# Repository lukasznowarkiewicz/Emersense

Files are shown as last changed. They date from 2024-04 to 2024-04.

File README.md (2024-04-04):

# Emersense - Emergency Vehicle Detection System
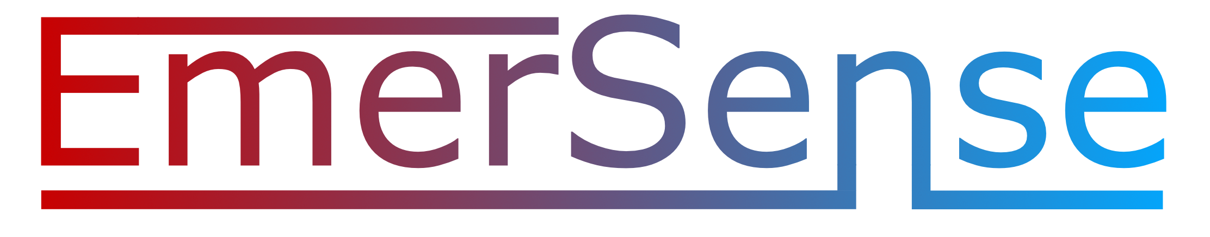
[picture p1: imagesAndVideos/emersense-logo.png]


## Introduction

Emersense is an innovative project developed by a group of dedicated students from Poznan University of Technology. Initiated during the challenging times of the pandemic, this project was brought to life entirely remotely by a team of four members located in four different cities across Poland. The project was realized as part of a competition organized by Enactus Poland, within the framework of the Enactus student organization, which promotes socially responsible projects.

The primary issue that Emersense aims to address is the often too-late response to an approaching emergency vehicle. This problem poses a significant risk not only to the efficiency of emergency services but also to the safety of both the emergency responders and the general public. By leveraging advanced technology, Emersense seeks to provide a timely warning about approaching emergency vehicles, thereby improving response times and reducing the potential for accidents.

## Solution Overview

The core of the Emersense project is a device that uses microphone data to detect emergency vehicle sirens amidst urban noise. It distinguishes these sirens from other sounds such as street noise and engine sounds, and informs the driver of their presence.

- **Siren Detection:** Utilizes signal processing to identify emergency vehicle sirens.
- **Driver Alert:** Notifies the driver through auditory and visual signals.

## Initial Trials on a PC

At the start, we gathered lots of different siren sounds from the internet to build a sound database for Emersense. We quickly found out there's a huge variety of siren sounds. These sounds not only change from one emergency vehicle to another but also differ a lot between countries. There wasn’t even a standard for sirens within the EU. Despite these challenges, we began with the easiest siren sounds to recognize: the sweep and two-tone sirens.

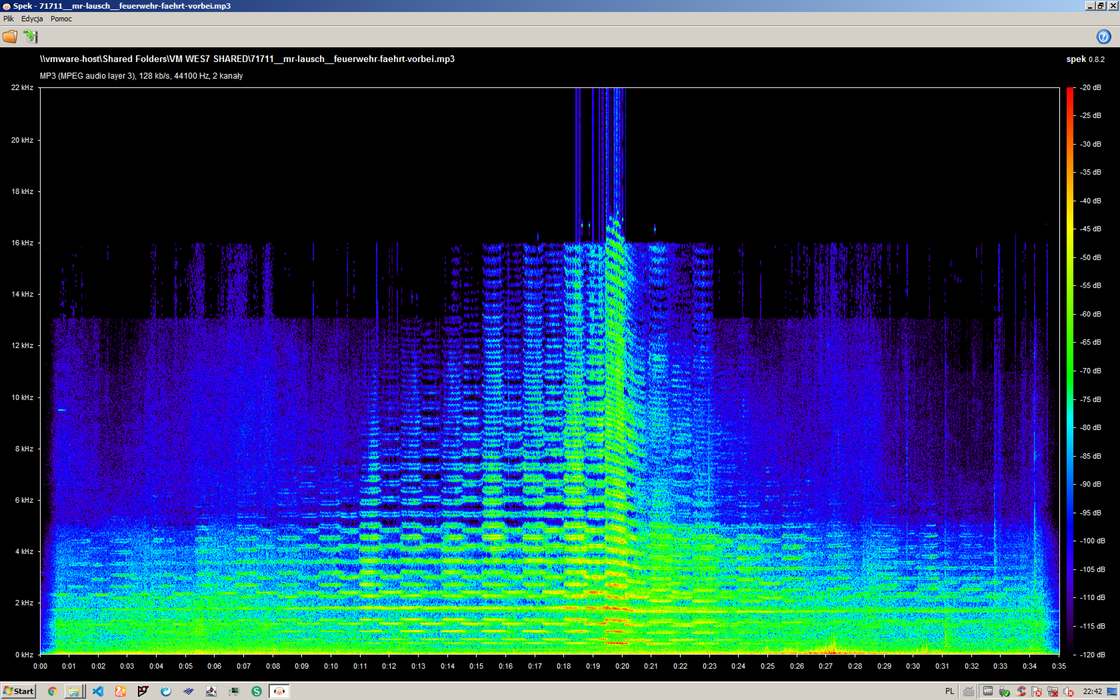
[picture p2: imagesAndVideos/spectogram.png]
Spectrogram of siren


Our first try at figuring out the siren sounds used the FFT (Fast Fourier Transform) library on a computer with an 8-core Intel Core i7 processor. But, we soon realized it was too complex to process the sounds in real time on this setup. So, we switched to the DFT (Discrete Fourier Transform), which was faster and allowed us to make our first successful programs that could recognize two-tone sirens.

Knowing we couldn’t use Python code directly on a microcontroller for the final product, we started to look into low-power hardware that could work for the Emersense device. This was a big step because it helped us focus on finding a solution that could actually be built into a real, working device.

## Trials on the DevKit

After our initial success, we started writing similar code in C for the ESP32 microcontroller. Our first goal was to get a correct spectrum of the signal received from the microphone. 

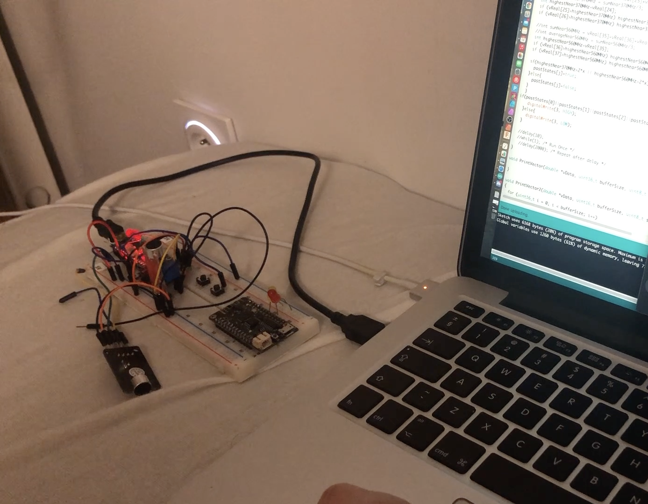
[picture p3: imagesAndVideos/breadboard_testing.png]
Breadboard testing


We soon realized that an electret microphone with an operational amplifier connected to an analog input was giving very inconsistent results. After trying out three more microphone modules, which all produced similarly poor outcomes, we switched to a MEMS microphone that uses the I2S bus - the INMP441. 

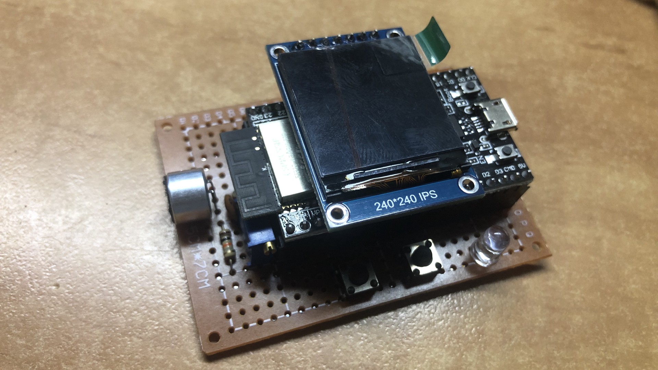
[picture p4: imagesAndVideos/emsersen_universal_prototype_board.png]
DevKit testing


Eventually, we managed to get preliminarily satisfying results and programmed it to recognize one type of two-tone siren.

https://github.com/lukasznowarkiewicz/Emersense/assets/82212257/3abe5127-96e8-427c-9536-c156f4cf9e74

## Device on a Custom PCB

As the project evolved, it became necessary for the device not only to function efficiently but also to have an appealing marketing appearance. This required moving away from the mess of wires on breadboards and prototype boards and towards giving the device a sensible shape on a custom PCB, along with a fitting enclosure.

### PCB Design

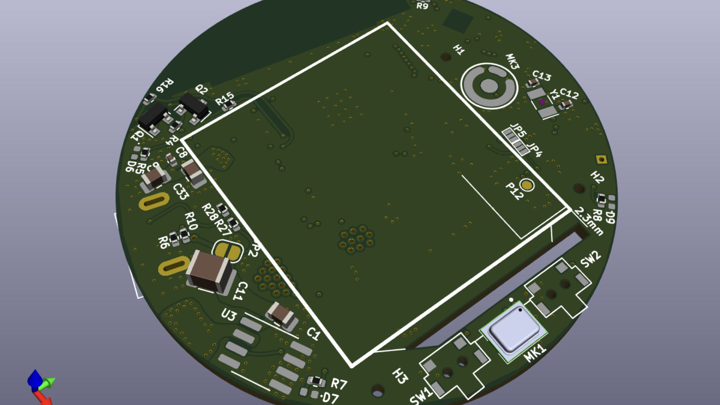
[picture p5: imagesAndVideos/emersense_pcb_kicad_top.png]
PCB Top View

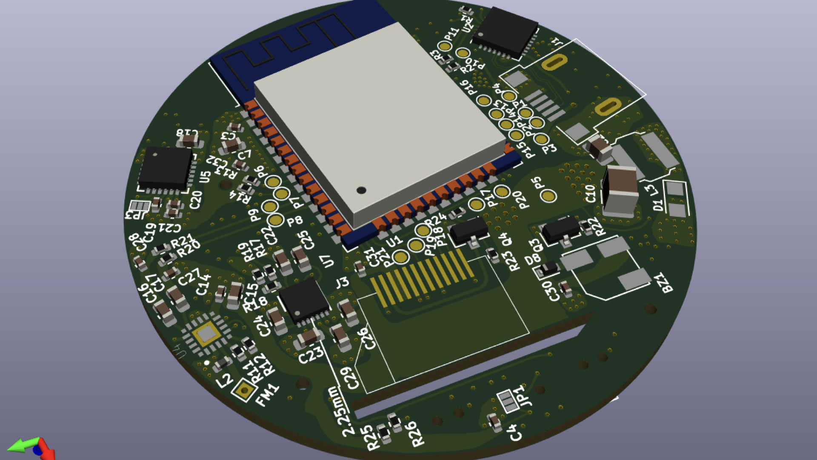
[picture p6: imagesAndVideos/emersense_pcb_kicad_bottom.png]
PCB Bottom View

Schematic

- **Software:** The PCB was designed in KiCad 5.
- **Components:**
  - **ESP32 Module:** Core processing unit.
  - **CP2102N:** For USB connectivity, allowing programming and data reading through the console.
  - **XL1509:** A converter for stepping down from 5V to 3.3V.
  - **SI4713 FM Transmitter with RDS:** We planned to generate an 'Traffic' RDS signal, which could switch nearby car radios to a traffic channel to broadcast information about the approaching emergency vehicle.
  - **MPU-6050:** For activating energy-saving mode when the vehicle is stationary for an extended period.
  - **INMP441 Digital Microphone and a Legacy Electret Microphone with Amplifier:** To test if the PCB, without the mess of wires, would collect fewer interferences.
  - **SPI 1.3 inch LCD Display (240x240 pixels) with ST7789s Controller.**
- **Shape and Assembly:** The PCB was designed in a round form to accommodate two versions of the device. It was ordered from JLCPCB, with parts from LCSC and manually assembled using a hand-operated pick and place machine.

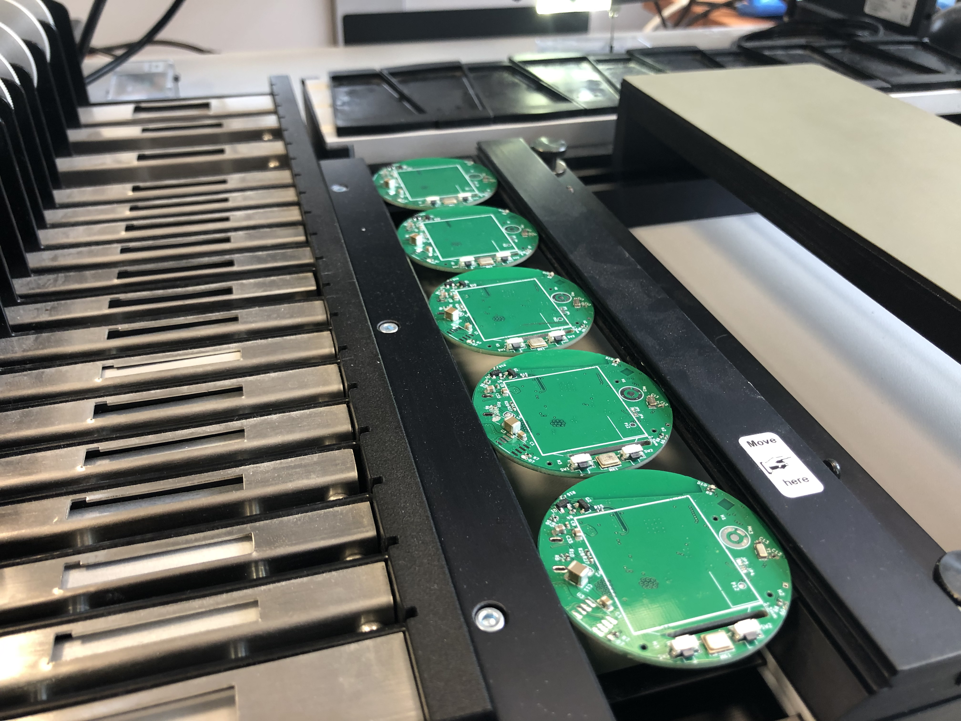
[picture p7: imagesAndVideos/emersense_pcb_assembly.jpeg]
PCB Assembly


https://github.com/lukasznowarkiewicz/Emersense/assets/82212257/2ed6d327-44b5-4cf7-a69e-9ff8332732e1

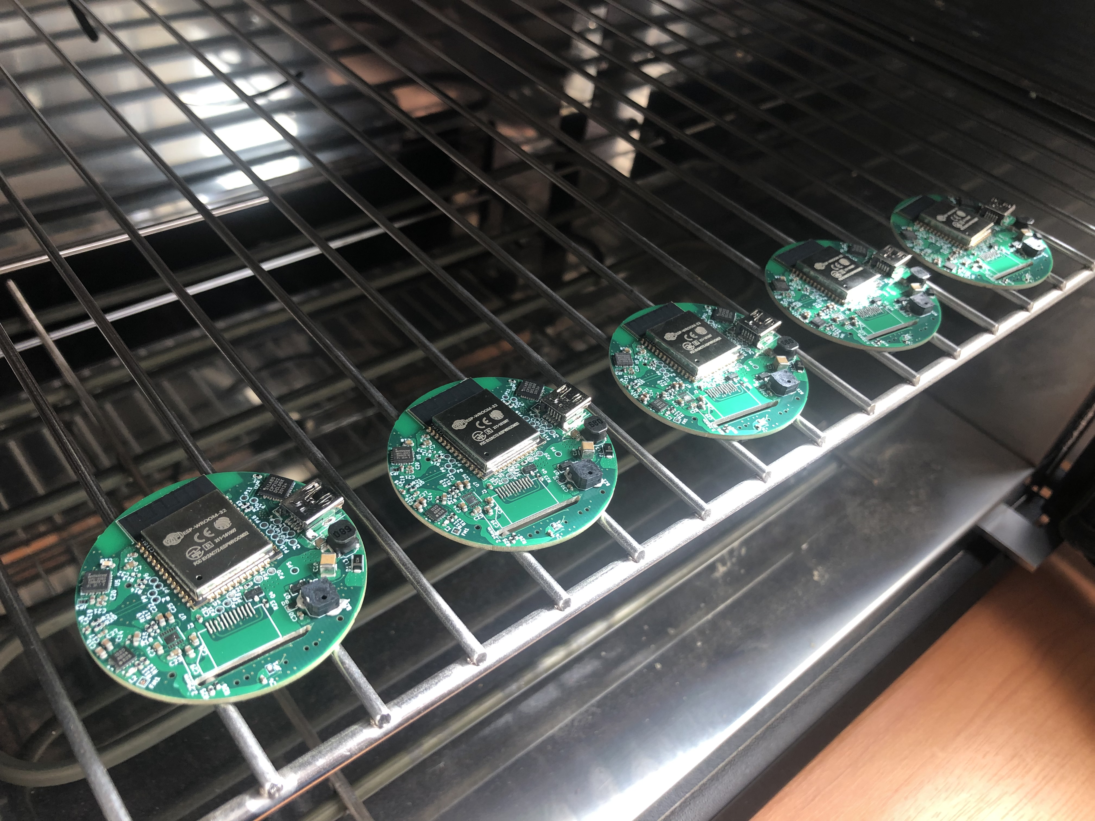
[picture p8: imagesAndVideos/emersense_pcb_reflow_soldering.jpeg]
Reflow Soldering


### Enclosure Design

- **Software:** Designed in Fusion 360.
- **Versions:** Two variants were created - one to be mounted on the windshield and another to be inserted into the cigarette lighter socket.
- **Manufacturing:** The enclosures were printed on an Anycubic Photon S SLA printer and cured under a UV nail lamp for hardening.

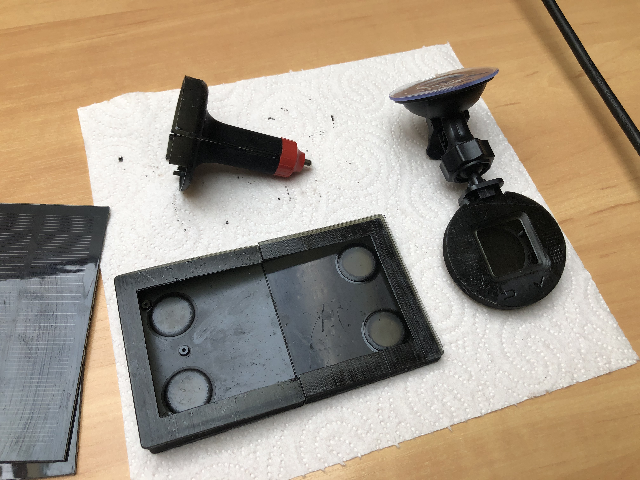
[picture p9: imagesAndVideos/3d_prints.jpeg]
3D Prints

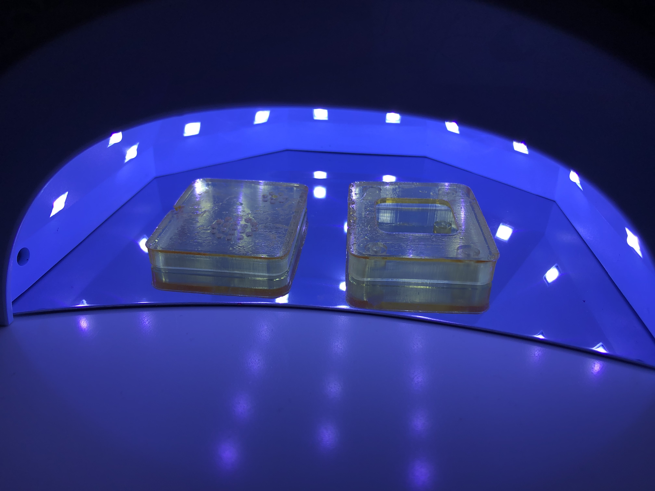
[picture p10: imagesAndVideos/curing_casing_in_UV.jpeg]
Curing Casing in UV

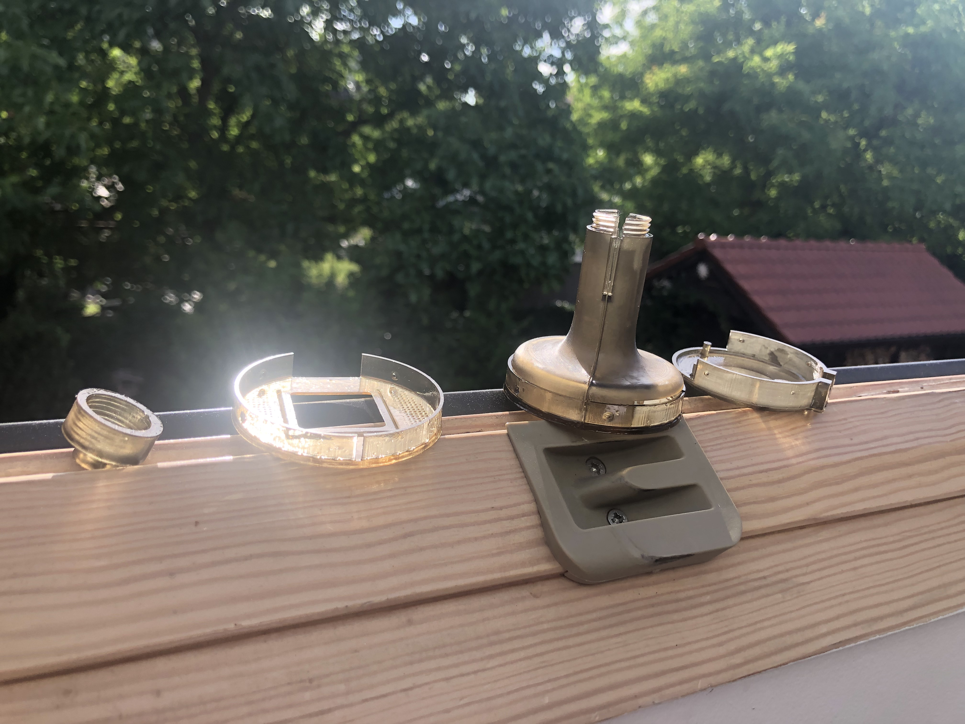
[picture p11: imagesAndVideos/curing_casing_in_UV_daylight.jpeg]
Curing Casing in UV Daylight


This stage marked a significant advancement towards finalizing the product, focusing on both functionality and aesthetics.

## Testing and Further Work

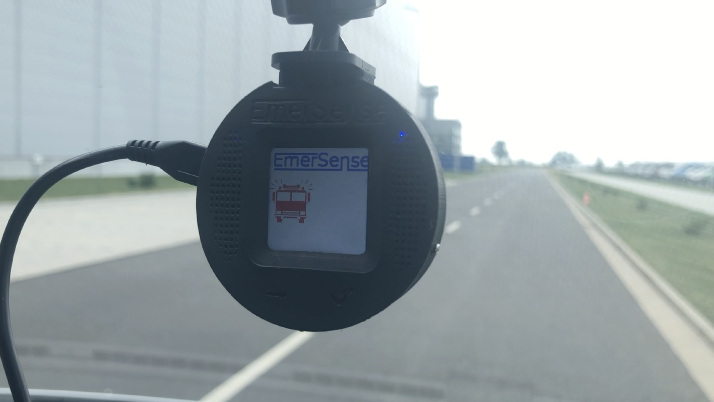
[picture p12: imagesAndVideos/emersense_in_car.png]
Testing in Car

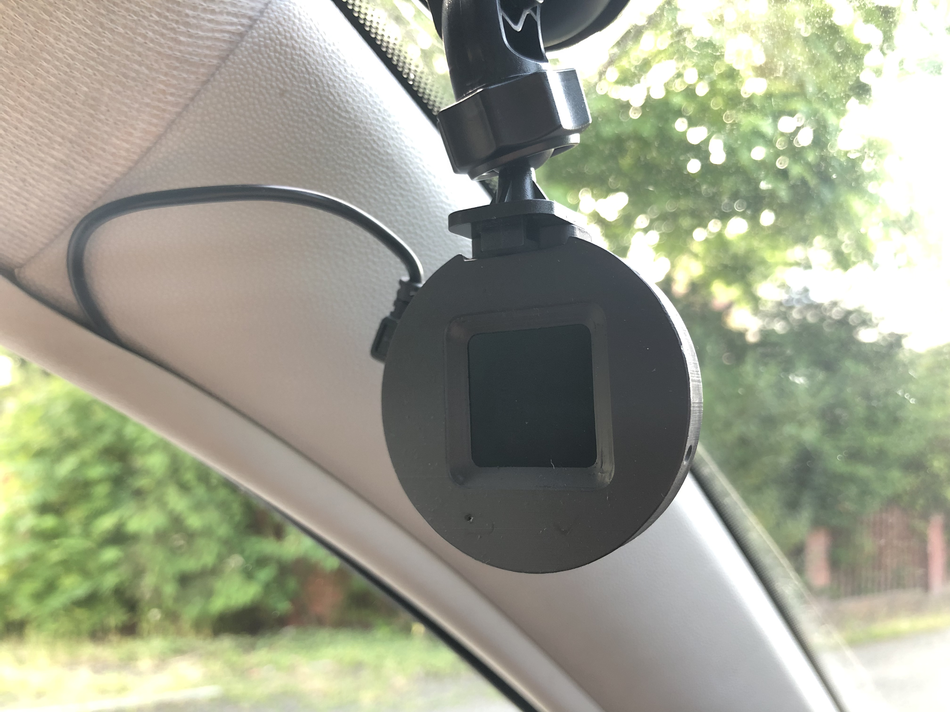
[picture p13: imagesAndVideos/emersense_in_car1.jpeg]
In-Car Device


This phase was particularly challenging. We were focused on improving the software, but progress was slow. Even with relatively simple sirens, it was difficult to balance the system's sensitivity to quickly detect sirens without being triggered by random noises. More accurate methods, like the autocorrelation function between the spectrum of a reference signal and the captured signal, were computationally complex, and we couldn't implement them to work in real-time.

At the same time, the competition, which emphasized presenting the project rather than its operational success, demanded a significant amount of time for preparing presentations and other materials. This took away valuable time that could have been spent on development. Moreover, a complete misunderstanding of the problem we were working on and what it takes to work on such projects by the leadership of the student organization didn't make things easier.

https://github.com/lukasznowarkiewicz/Emersense/assets/82212257/557e5657-ebb7-40b5-8d4b-21e4bb15feb9

Considering all these challenges, after presenting our project at the competition, we decided to close the project. Interestingly, after we had stopped working on it, the rector of the Poznan University of Technology showed interest in the device, having heard about it in local TV news. He wanted to assemble a team of doctors and PhD students to assist in the project. However, by that time, we had already concluded the project, seeing no further prospects for it. This experience was a valuable lesson on how institutions like universities can sometimes fall short in supporting such projects.

## Summary - Conclusions

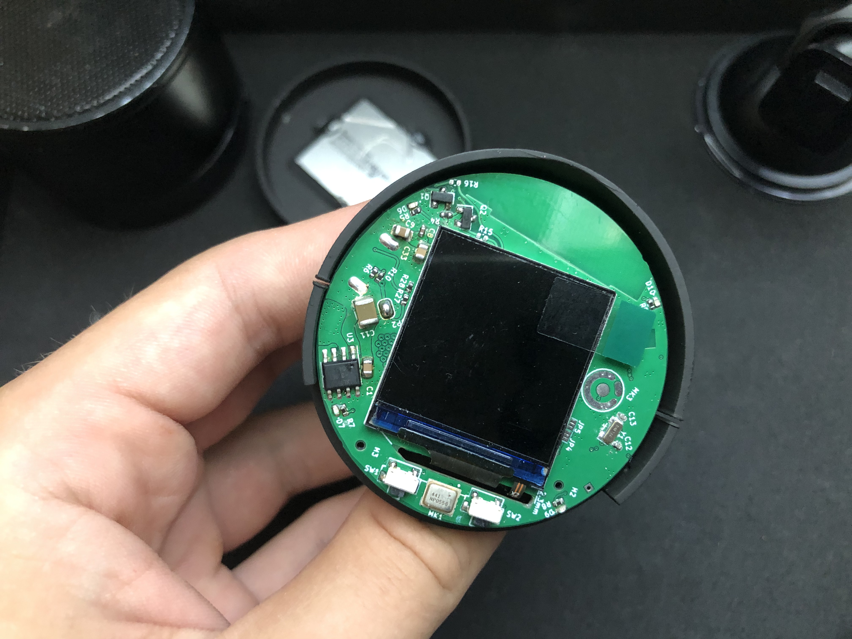
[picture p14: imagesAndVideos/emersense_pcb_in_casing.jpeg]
PCB in Casing

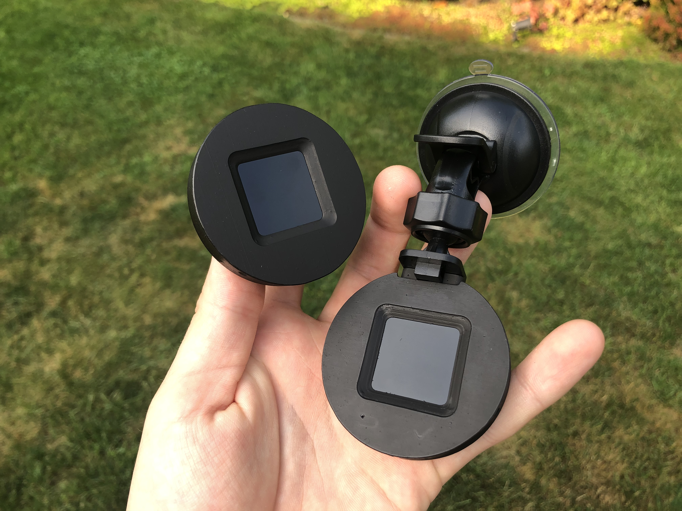
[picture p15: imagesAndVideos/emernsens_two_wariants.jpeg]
Two Variants

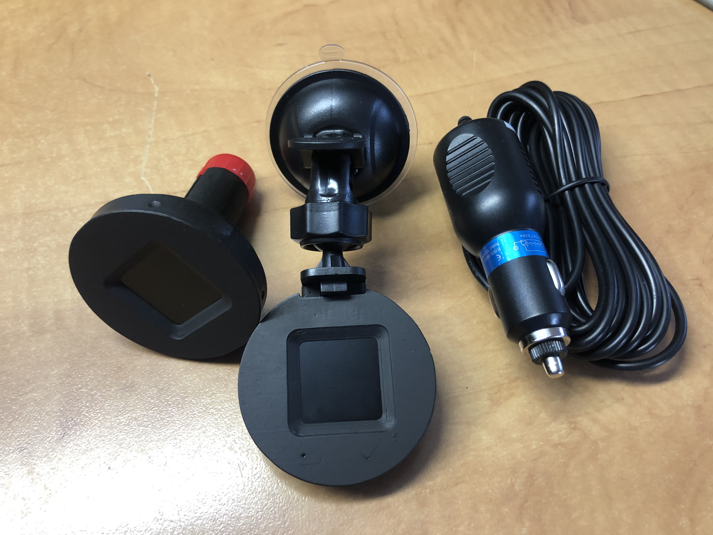
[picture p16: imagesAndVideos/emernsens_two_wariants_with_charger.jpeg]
With Charger Variant


Reflecting on the Emersense project, we came away with several crucial insights. A major gap in our approach was the lack of a clear business model, an oversight that might have been mitigated by considering the device as part of a larger integrated system. The complexity of distinguishing emergency vehicle sirens—a problem we initially underestimated—proved to be a significant challenge. Our discussions with industry professionals, including a director from a leading automotive computer company, highlighted the universal struggle with this issue. Their interest in collaboration pointed to its relevance, yet the continued absence of such technology in cars indicates a widespread challenge.

Market demand for the device remained uncertain, raising questions about its commercial viability. Although integrating the technology with a charger offered a potential pathway, the standalone module concept failed to meet expectations. This was a lesson in both the technological hurdles and the importance of clear value propositions in product design.

A critical shortcoming in our development process was the organization of software work, particularly the lack of emphasis on automated testing. Effective development practices should have prioritized automated tests for every software version, introducing additional complexities such as hardware simulation and the input of audio in the I2S format. This approach would not only have streamlined troubleshooting but also ensured more rigorous validation of our system's performance.

The project's discontinuation, while disheartening, provided invaluable lessons on navigating the intricate balance between technical innovation and commercial strategy in the automotive technology space.

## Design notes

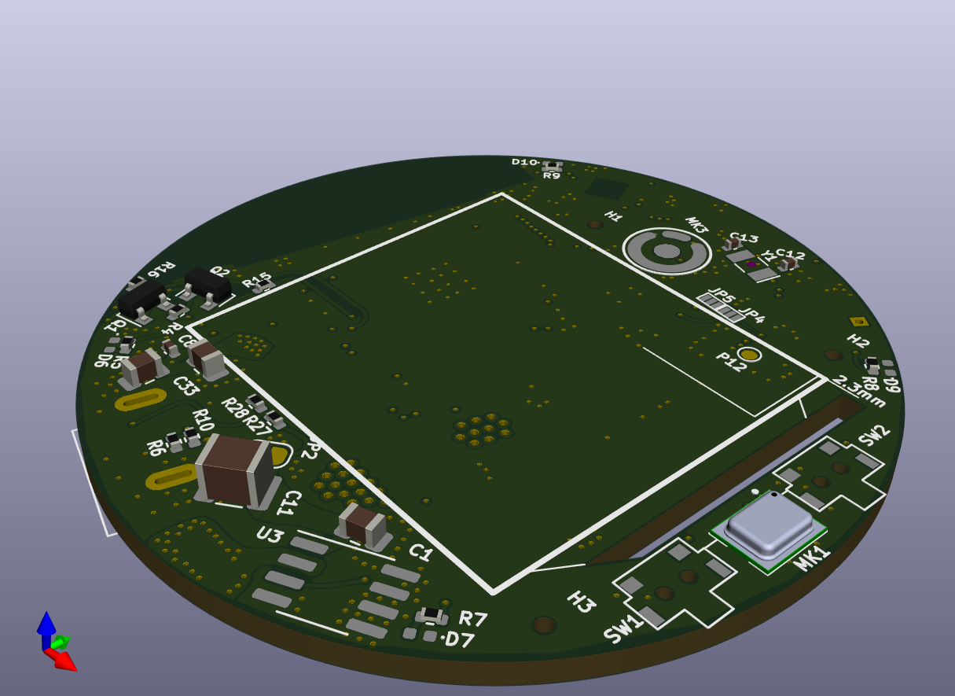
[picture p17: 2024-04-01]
Hardware-electronics/renders/Emersense_V1_1.png

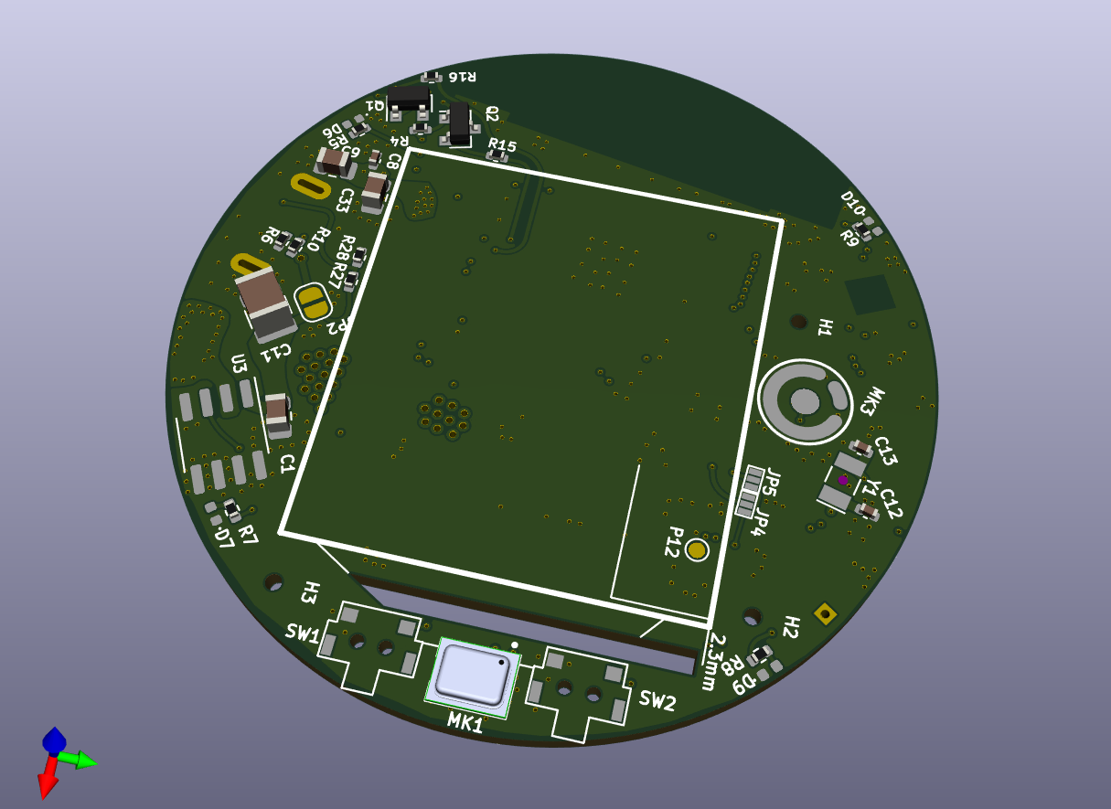
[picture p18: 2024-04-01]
Hardware-electronics/renders/Emersense_V1_2.png

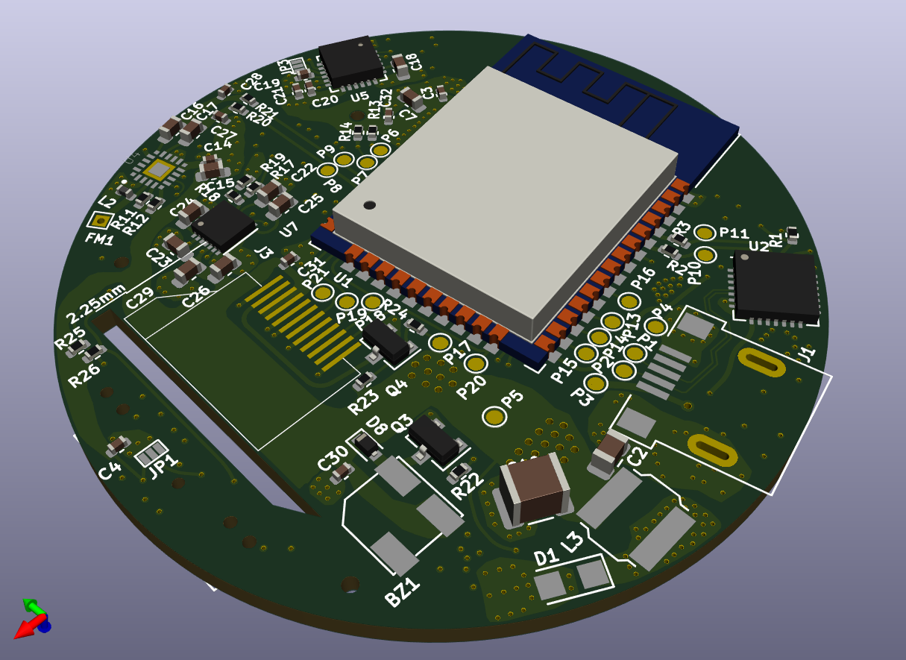
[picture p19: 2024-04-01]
Hardware-electronics/renders/Emersense_V1_5.png

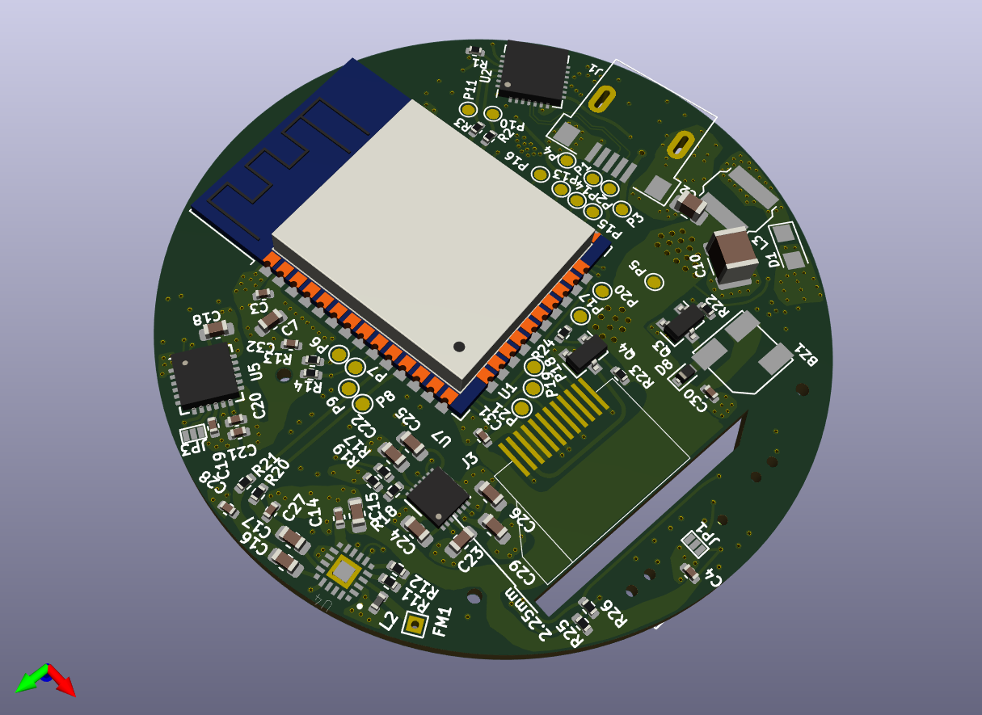
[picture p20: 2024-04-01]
Hardware-electronics/renders/Emersense_V1_4.png

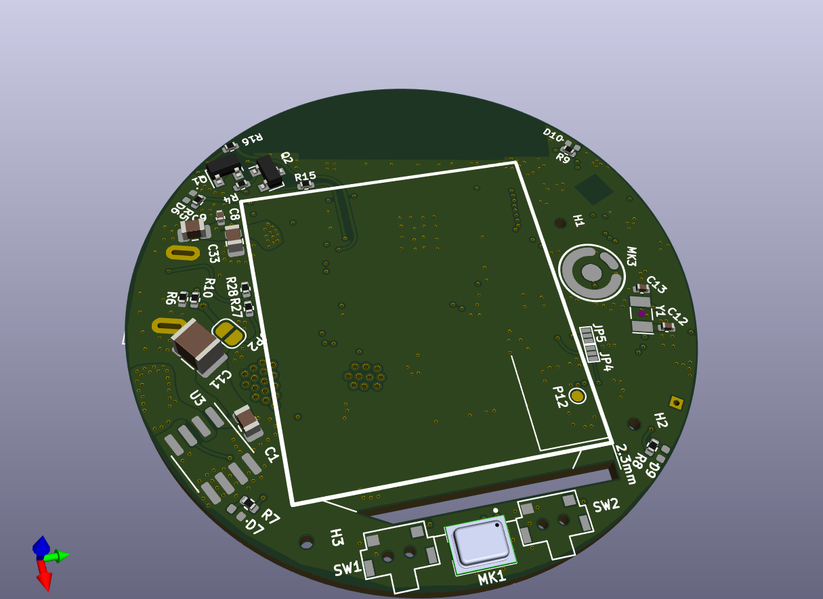
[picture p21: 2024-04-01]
Hardware-electronics/renders/Emersense_V1_3.png

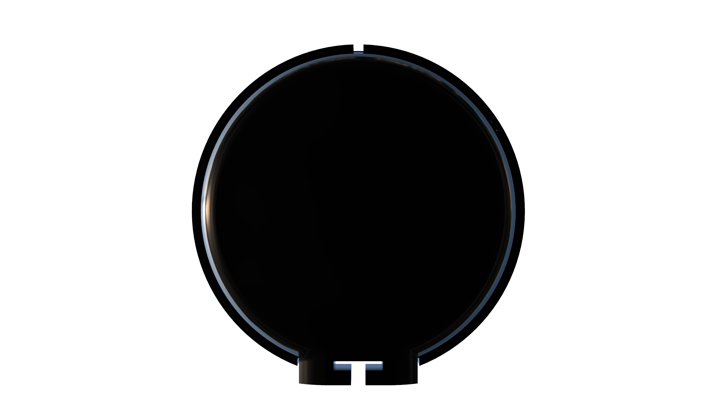
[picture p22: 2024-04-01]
Hardware-mechanical/windshield_version/na_szybe_rev1_00022.tif

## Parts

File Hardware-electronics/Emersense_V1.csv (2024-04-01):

Reference | Quantity | Value | Footprint | Datasheet | Link | Price | StoreName | minimum_order | MANUFACTURER | MAXIMUM_PACKAGE_HEIGHT | PARTREV | STANDARD | TempCoeff | Voltage
BZ1 | 1 | Buzzer | Emersense:MLT-5030 | ~ | https://lcsc.com/product-detail/Buzzers_Jiangsu-Huaneng-Elec-MLT-5030_C95297.html | 0,5843 | LCSC | 1 |  |  |  |  | nd
C10 | 1 | 100u/6.3V | Capacitor_SMD:C_1210_3225Metric | ~ | https://lcsc.com/product-detail/Multilayer-Ceramic-Capacitors-MLCC-SMD-SMT_Murata-Electronics-GRM32ER60J107ME20L_C88154.html | 0,1763 | LCSC | 1 |  |  |  |  | X5R | 6.3V
C11 | 1 | 100u/16V | Capacitor_SMD:C_1210_3225Metric | ~ | https://lcsc.com/product-detail/Multilayer-Ceramic-Capacitors-MLCC-SMD-SMT_Taiyo-Yuden-EMK325ABJ107MM-P_C90143.html | 0,6943 | LCSC | 1 |  |  |  |  | X5R | 16V
C12 C13 | 2 | 20p | Capacitor_SMD:C_0402_1005Metric | ~ | https://lcsc.com/product-detail/Multilayer-Ceramic-Capacitors-MLCC-SMD-SMT_CCTC-TCC0402COG200J500AT_C880615.html | 0,0014 | LCSC | 100 |  |  |  |  | C0G | 50V
C14 C32 | 2 | 22n | Capacitor_SMD:C_0402_1005Metric | ~ | https://lcsc.com/product-detail/Multilayer-Ceramic-Capacitors-MLCC-SMD-SMT_TDK-C1005X7R1C104KT000F_C338032.html | 0,0195 | LCSC | 50 |  |  |  |  | X7R
C15 | 1 | 10u | Capacitor_SMD:C_0603_1608Metric | ~ | https://lcsc.com/product-detail/Multilayer-Ceramic-Capacitors-MLCC-SMD-SMT_Samsung-Electro-Mechanics-CL10A106MQ8NNNC_C1691.html | 0,0105 | LCSC | 50 |  |  |  |  | X5R
C16 C17 C22 | 3 | 470n | Capacitor_SMD:C_0603_1608Metric | ~ | https://lcsc.com/product-detail/Multilayer-Ceramic-Capacitors-MLCC-SMD-SMT_YAGEO-CC0603JRX7R6BB474_C519557.html | 0,018 | LCSC | 20 |  |  |  |  | X7R | 10V
C18 | 1 | 2.2n | Capacitor_SMD:C_0603_1608Metric | ~ | https://lcsc.com/product-detail/Multilayer-Ceramic-Capacitors-MLCC-SMD-SMT_SAMSUNG_CL10B222KB8NNNC_2-2nF-222-10-50V_C16033.html | 0,0059 | LCSC | 50 |  |  |  |  | X7R | 50V
C1 C2 | 2 | 100n/50V | Capacitor_SMD:C_0805_2012Metric | ~ | https://lcsc.com/product-detail/Multilayer-Ceramic-Capacitors-MLCC-SMD-SMT_Samsung-Electro-Mechanics-CL21B104KBFNNNE_C136621.html | 0,0093 | LCSC | 50 |  |  |  |  | X7R | 50V
C20 C30 | 2 | 10n | Capacitor_SMD:C_0402_1005Metric | ~ | https://lcsc.com/product-detail/Others_Samsung-Electro-Mechanics_CL05B103KB5VPNC_Samsung-Electro-Mechanics-CL05B103KB5VPNC_C307330.html | 0,0116 | LCSC | 50 |  |  |  |  | X7R | 50V
C24 C25 C26 | 3 | 100n | Capacitor_SMD:C_0603_1608Metric | ~ | https://lcsc.com/product-detail/Multilayer-Ceramic-Capacitors-MLCC-SMD-SMT_Samsung-Electro-Mechanics-CL10B104KB8SNNC_C570192.html | 0,0048 | LCSC | 50 |  |  |  |  | X7R | 50V
C27 C28 | 2 | 2.2n | Capacitor_SMD:C_0402_1005Metric | ~ | https://lcsc.com/product-detail/Multilayer-Ceramic-Capacitors-MLCC-SMD-SMT_CCTC-TCC0402X7R222K500AT_C915853.html | 0,0013 | LCSC | 100 |  |  |  |  | X7R | 50V
C29 | 1 | 10n | Capacitor_SMD:C_0603_1608Metric | ~ | https://lcsc.com/product-detail/Multilayer-Ceramic-Capacitors-MLCC-SMD-SMT_CCTC-TCC0603X7R103M500CT_C376807.html | 0,0027 | LCSC | 100 |  |  |  |  | X7R | 50V
C33 | 1 | 10n | Capacitor_SMD:C_0805_2012Metric | ~ | https://lcsc.com/product-detail/New-Arrivals_CCTC-TCC0805X7R103M500DT_C376921.html | 0,0056 | LCSC | 50 |  |  |  |  | X7R | 50V
C3 C4 C8 C19 C21 C31 | 6 | 100n | Capacitor_SMD:C_0402_1005Metric | ~ | https://lcsc.com/product-detail/Multilayer-Ceramic-Capacitors-MLCC-SMD-SMT_TDK-C1005X7R1C104KT000F_C338032.html | 0,0195 | LCSC | 50 |  |  |  |  | X7R
C7 C23 | 2 | 2.2u | Capacitor_SMD:C_0603_1608Metric | ~ | https://lcsc.com/product-detail/Multilayer-Ceramic-Capacitors-MLCC-SMD-SMT_Samsung-Electro-Mechanics-CL10B225KP8NNNC_C100082.html | 0,0177 | LCSC | 50 |  |  |  |  | X7R
C9 | 1 | 10u | Capacitor_SMD:C_0805_2012Metric | ~ | https://lcsc.com/product-detail/Multilayer-Ceramic-Capacitors-MLCC-SMD-SMT_Samsung-Electro-Mechanics-CL21B106KQQNNNE_C100083.html | 0,0268 | LCSC | 20 |  |  |  |  | X7R
D1 | 1 | SS34 | Emersense:SOD-123FL | ~ | https://lcsc.com/product-detail/Schottky-Barrier-Diodes-SBD_BORN-DSS34_C511866.html | 0,0352 | LCSC | 20
D10 | 1 | LED4 | Diode_SMD:D_0402_1005Metric | ~ | https://lcsc.com/product-detail/Light-Emitting-Diodes-LED_TOGIALED-TJ-S1005SW4TGLC6B-A5_C273603.html | 0,0487 | LCSC | 10
D6 | 1 | LED1 | Diode_SMD:D_0402_1005Metric | ~ | https://lcsc.com/product-detail/Light-Emitting-Diodes-LED_TOGIALED-TJ-S1005SW4TGLC6B-A5_C273603.html | 0,0487 | LCSC | 10
D7 | 1 | LED2 | Diode_SMD:D_0402_1005Metric | ~ | https://lcsc.com/product-detail/Light-Emitting-Diodes-LED_TOGIALED-TJ-S1005SW4TGLC6B-A5_C273603.html | 0,0487 | LCSC | 10
D8 | 1 | 1N4148 | Diode_SMD:D_SOD-523 | ~ | https://lcsc.com/product-detail/Switching-Diode_JSMSEMI-1N4148WT_C917006.html | 0,0103 | LCSC | 50
D9 | 1 | LED3 | Diode_SMD:D_0402_1005Metric | ~ | https://lcsc.com/product-detail/Light-Emitting-Diodes-LED_TOGIALED-TJ-S1005SW4TGLC6B-A5_C273603.html | 0,0487 | LCSC | 10
FM1 | 1 | FM Antenna | TestPoint:TestPoint_THTPad_1.0x1.0mm_Drill0.5mm | ~ |  |  | -
H1 H2 H3 | 3 | MountingHole | Emersense:M1_screw | ~
J1 | 1 | USB_B_Mini | Emersense:U-M-M5DS-W-4 | ~ | https://lcsc.com/product-detail/USB-Connectors_Korean-Hroparts-Elec-U-M-M5DS-W-4_C188818.html | 0,157 | LCSC | 1
J3 | 1 | Conn_01x12 | Emersense:SCREEN_Footprint_extended | ~ | https://pl.aliexpress.com/item/32909172341.html | 3,14 | Aliexpress | 1
JP1 | 1 | LR | Emersense:3_jumper_1 | ~
JP2 | 1 | Jumper | Jumper:SolderJumper-2_P1.3mm_Open_RoundedPad1.0x1.5mm | ~
JP3 | 1 | AD_MPU | Emersense:3_jumper_1 | ~
JP4 | 1 | Attack/Release | Emersense:3_jumper_1 | ~
JP5 | 1 | GAIN | Emersense:3_jumper_1 | ~
L2 | 1 | 120n | Inductor_SMD:L_0402_1005Metric | ~ | https://lcsc.com/product-detail/HF-Inductors_FH-Guangdong-Fenghua-Advanced-Tech-VHF100505HQR12JT_C268315.html | 0,0042 | LCSC | 50 |  |  |  |  | nd
L3 | 1 | 68u | Emersense:SWPA5040S680MT | ~ | https://lcsc.com/product-detail/Power-Inductors_Sunlord-SWPA5040S680MT_C86662.html | 0,1472 | LCSC | 5 |  |  |  |  | nd
MK1 | 1 | INMP441ACEZ-R7 | Emersense:MIC_INMP441ACEZ-R7 |  | gdzies w ali | 2 | Aliexpress | 1 | TDK InvenSense | 1.05 mm | 1.1 | Manufacturer Recommendations | nd
MK3 | 1 | MIC | Emersense:B4013AM423-093 | ~ | https://lcsc.com/product-detail/Electret-Condenser-Microphone_Goertek-B4013AM423-093_C233790.html | 0,1616 | LCSC | 1 |  |  |  |  | nd
P1 | 1 | USB1 | TestPoint:TestPoint_Pad_D1.0mm | ~
P10 | 1 | RX_S | TestPoint:TestPoint_Pad_D1.0mm | ~
P11 | 1 | TX_S | TestPoint:TestPoint_Pad_D1.0mm | ~
P12 | 1 | MIC_AMP | TestPoint:TestPoint_Pad_D1.0mm | ~
P13 | 1 | I2S_C | TestPoint:TestPoint_Pad_D1.0mm | ~
P14 | 1 | I2S_D | TestPoint:TestPoint_Pad_D1.0mm | ~
P15 P22 | 2 | I2S_WS | TestPoint:TestPoint_Pad_D1.0mm | ~
P16 | 1 | Buzzer | TestPoint:TestPoint_Pad_D1.0mm | ~
P17 | 1 | Display | TestPoint:TestPoint_Pad_D1.0mm | ~
P18 | 1 | LCD_D | TestPoint:TestPoint_Pad_D1.0mm | ~
P19 | 1 | LCD_CLK | TestPoint:TestPoint_Pad_D1.0mm | ~
P2 | 1 | USB2 | TestPoint:TestPoint_Pad_D1.0mm | ~
P20 | 1 | LCD_RST | TestPoint:TestPoint_Pad_D1.0mm | ~
P21 | 1 | LCD_DC | TestPoint:TestPoint_Pad_D1.0mm | ~
P3 | 1 | USB_P | TestPoint:TestPoint_Pad_D1.0mm | ~
P4 | 1 | USB_G | TestPoint:TestPoint_Pad_D1.0mm | ~
P5 | 1 | PWR33 | TestPoint:TestPoint_Pad_D1.0mm | ~
P6 P23 | 2 | I2C_D | TestPoint:TestPoint_Pad_D1.0mm | ~
P7 | 1 | I2C_C | TestPoint:TestPoint_Pad_D1.0mm | ~
P8 | 1 | DAC_O1 | TestPoint:TestPoint_Pad_D1.0mm | ~
P9 | 1 | DAC_O2 | TestPoint:TestPoint_Pad_D1.0mm | ~
Q1 Q2 | 2 | S8050 | Emersense:SOT-23-R | http://www.unisonic.com.tw/datasheet/S8050.pdf | https://lcsc.com/product-detail/Transistors-NPN-PNP_Guangdong-Hottech-S8050_C181158.html | 0,0094 | LCSC | 50
Q3 Q4 | 2 | MMBT2222A | Emersense:SOT-23-R | https://www.onsemi.com/pub/Collateral/PN2222-D.PDF | https://lcsc.com/product-detail/Transistors-NPN-PNP_BORN-MMBT2222A_C511875.html | 0,0167 | LCSC | 50
R11 R12 R23 | 3 | 10k | Resistor_SMD:R_0402_1005Metric | ~ | https://lcsc.com/product-detail/Chip-Resistor-Surface-Mount_Viking-Tech-CR-02FL6-10K_C406733.html | 0,0005 |  | 100
R13 R14 R25 R26 | 4 | 4.7k | Resistor_SMD:R_0402_1005Metric | ~ | https://lcsc.com/product-detail/Chip-Resistor-Surface-Mount_Viking-Tech-CR-02JL6-4K7_C406731.html | 0,0004 |  | 100
R15 R16 | 2 | NC | Resistor_SMD:R_0402_1005Metric | ~
R17 R22 | 2 | 2.2k | Resistor_SMD:R_0402_1005Metric | ~ | https://lcsc.com/product-detail/Chip-Resistor-Surface-Mount_UNI-ROYAL-Uniroyal-Elec-0402WGJ0222TCE_C25933.html | 0,0007 |  | 100
R18 | 1 | 150k | Resistor_SMD:R_0402_1005Metric | ~ | https://lcsc.com/product-detail/Chip-Resistor-Surface-Mount_150KR-1503-1_C93947.html | 0,0012 |  | 100
R19 | 1 | 100k | Resistor_SMD:R_0402_1005Metric | ~ | https://lcsc.com/product-detail/Chip-Resistor-Surface-Mount_UNI-ROYAL-Uniroyal-Elec-0402WGF1003TCE_C25741.html | 0,0008 |  | 100
R10 R20 R21 | 3 | 22k | Resistor_SMD:R_0402_1005Metric | ~ | https://lcsc.com/product-detail/Chip-Resistor-Surface-Mount_UNI-ROYAL-Uniroyal-Elec-0402WGJ0223TCE_C25547.html | 0,0007 |  | 100
R24 | 1 | 1k | Resistor_SMD:R_0402_1005Metric | ~ | https://lcsc.com/product-detail/Chip-Resistor-Surface-Mount_YAGEO-RC0402JR-071KL_C105637.html | 0,0006 |  | 100
R2 R3 | 2 | 0 | Resistor_SMD:R_0402_1005Metric | ~ | https://lcsc.com/product-detail/Chip-Resistor-Surface-Mount_YAGEO-RC0402JR-070RL_C60485.html | 0,0008 |  | 100
R1 R4 | 2 | 12k | Resistor_SMD:R_0402_1005Metric | ~ | https://lcsc.com/product-detail/Chip-Resistor-Surface-Mount_LIZ-Elec-CR0402JF0123G_C100582.html | 0,0008 |  | 100
R5 R7 R8 R9 | 4 | 3.6k | Resistor_SMD:R_0402_1005Metric | ~
R6 | 1 | 47k | Resistor_SMD:R_0402_1005Metric | ~ | https://lcsc.com/product-detail/Chip-Resistor-Surface-Mount_UNI-ROYAL-Uniroyal-Elec-0402WGJ0473TCE_C25563.html | 0,0007 |  | 100
SW1 SW2 | 2 | B1 | Emersense:TS-1086E | ~ | https://lcsc.com/product-detail/Tactile-Switches_XUNPU-TS-1086E-16_C455276.html | 0,0488 | LCSC | 10
U1 | 1 | ESP32-WROOM-32 | RF_Module:ESP32-WROOM-32 | https://www.espressif.com/sites/default/files/documentation/esp32-wroom-32_datasheet_en.pdf | https://pl.aliexpress.com/item/1005001621757745.html | 2,26 | Aliexpress | 1
U2 | 1 | CP2102N-A01-GQFN28 | Package_DFN_QFN:QFN-28-1EP_5x5mm_P0.5mm_EP3.35x3.35mm | https://www.silabs.com/documents/public/data-sheets/cp2102n-datasheet.pdf | https://pl.aliexpress.com/item/1005002483190969.html | 1,306 | Aliexpress | 5
U3 | 1 | XL1509-3.3 | Package_SO:SOP-8_3.76x4.96mm_P1.27mm |  | https://lcsc.com/product-detail/DC-DC-Converters_XLSEMI-XL1509-3-3E1_C74193.html | 0,2542 | LCSC | 1
U4 | 1 | SI4713 | Emersense:QFN50P300X300X60-21N |  | https://pl.aliexpress.com/item/4000018990696.html | 1,05 | Aliexpress | 5
U5 | 1 | MPU-6050 | Sensor_Motion:InvenSense_QFN-24_4x4mm_P0.5mm | https://store.invensense.com/datasheets/invensense/MPU-6050_DataSheet_V3%204.pdf | https://pl.aliexpress.com/item/1005001704112089.html | 0,44 | Aliexpress | 10
U7 | 1 | MAX9814ETD+T | Package_DFN_QFN:DFN-14-1EP_3x3mm_P0.4mm_EP1.78x2.35mm |  | https://pl.aliexpress.com/item/4001039764363.html | 0,58 | Aliexpress | 1 | MAXIM INTEGRATED |  | 3 | IPC 7351B
Y1 | 1 | 32.768 | Crystal:Crystal_SMD_G8-2Pin_3.2x1.5mm | ~ | https://lcsc.com/product-detail/SMD-Crystal-Resonators_KDS-Daishinku-KDS-DST310S-32-768KHz_C93232.html | 0,5104 | LCSC | 1

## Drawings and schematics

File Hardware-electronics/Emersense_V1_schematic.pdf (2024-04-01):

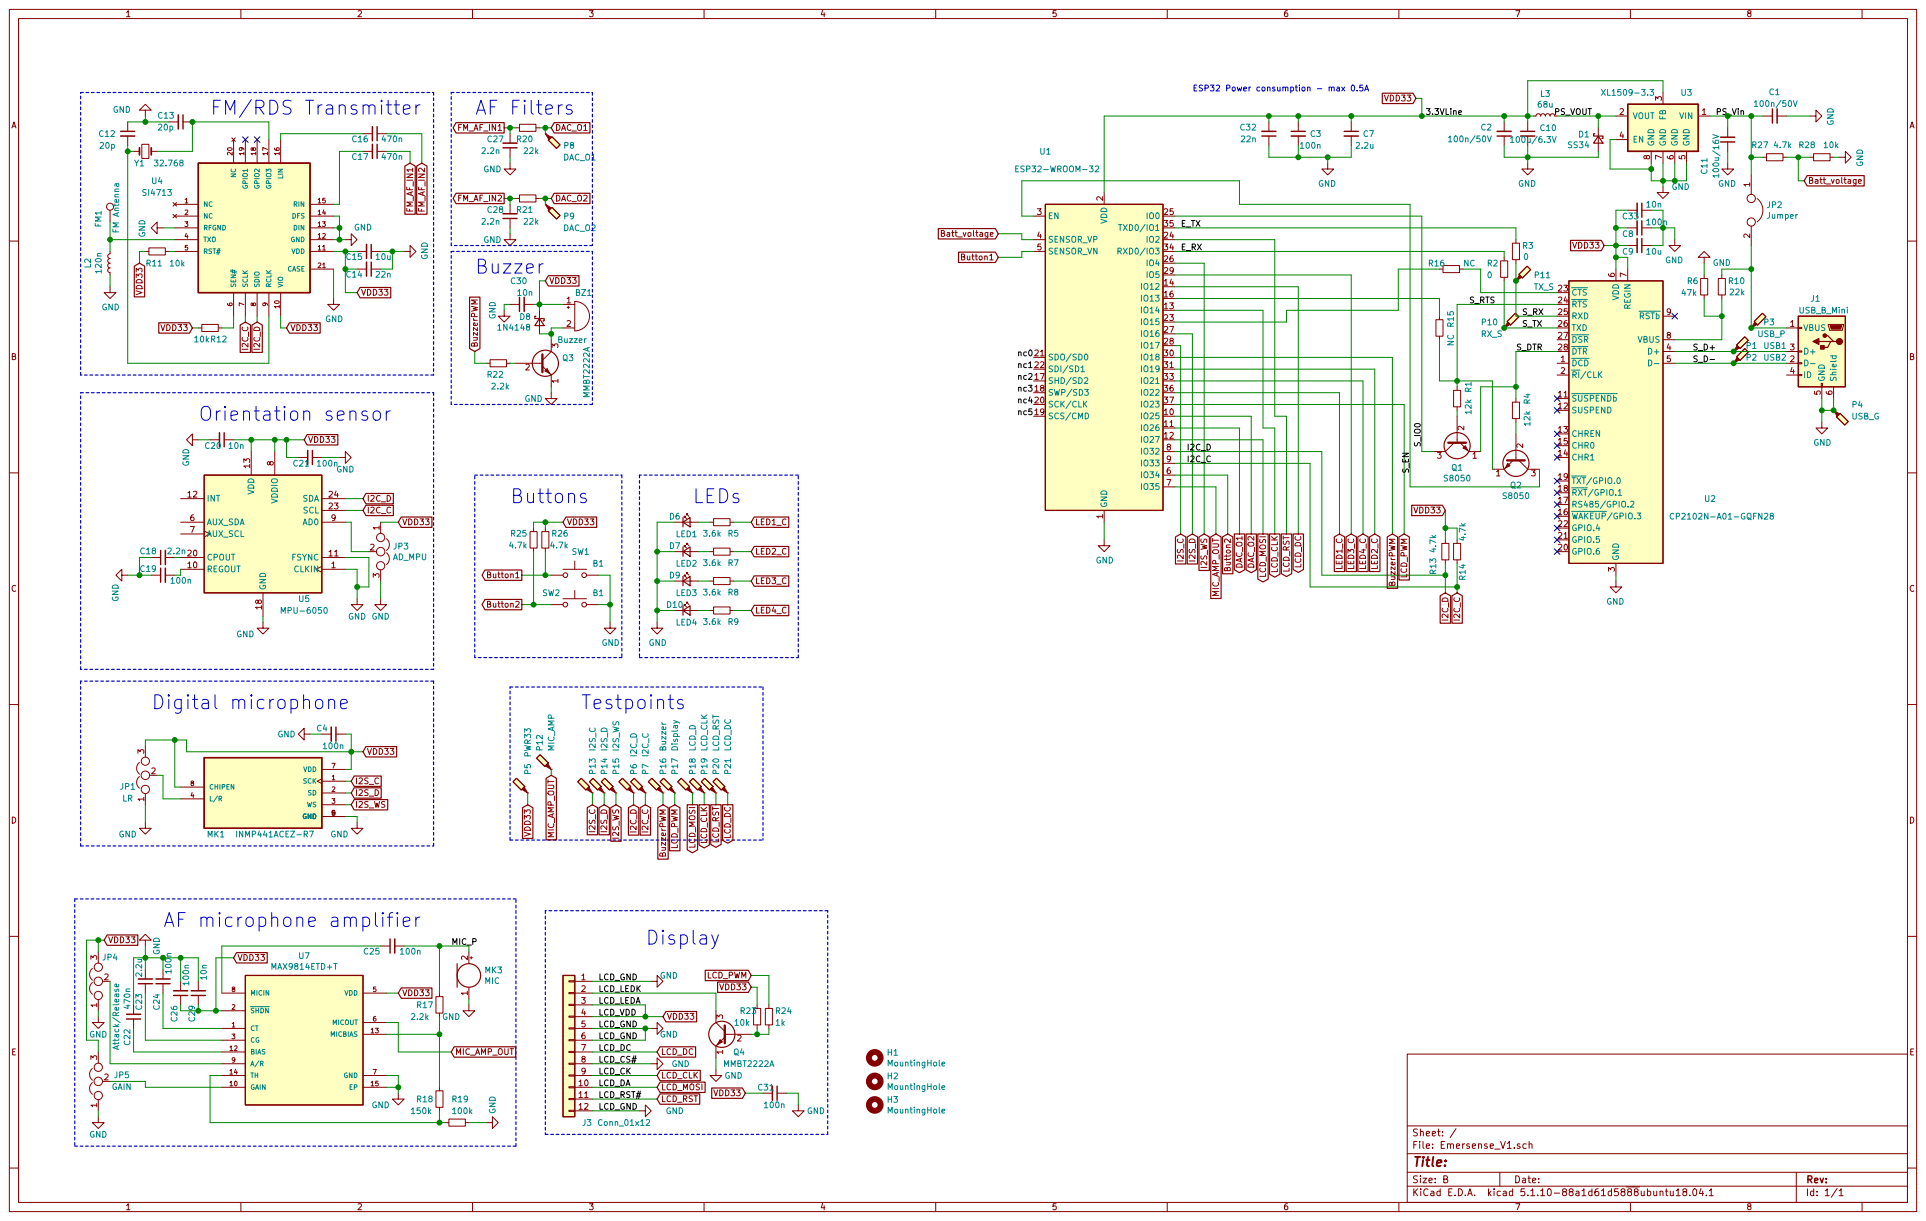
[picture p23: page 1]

2 SCK/CLK 20 SDO/SD0 21 SDI/SD1 22

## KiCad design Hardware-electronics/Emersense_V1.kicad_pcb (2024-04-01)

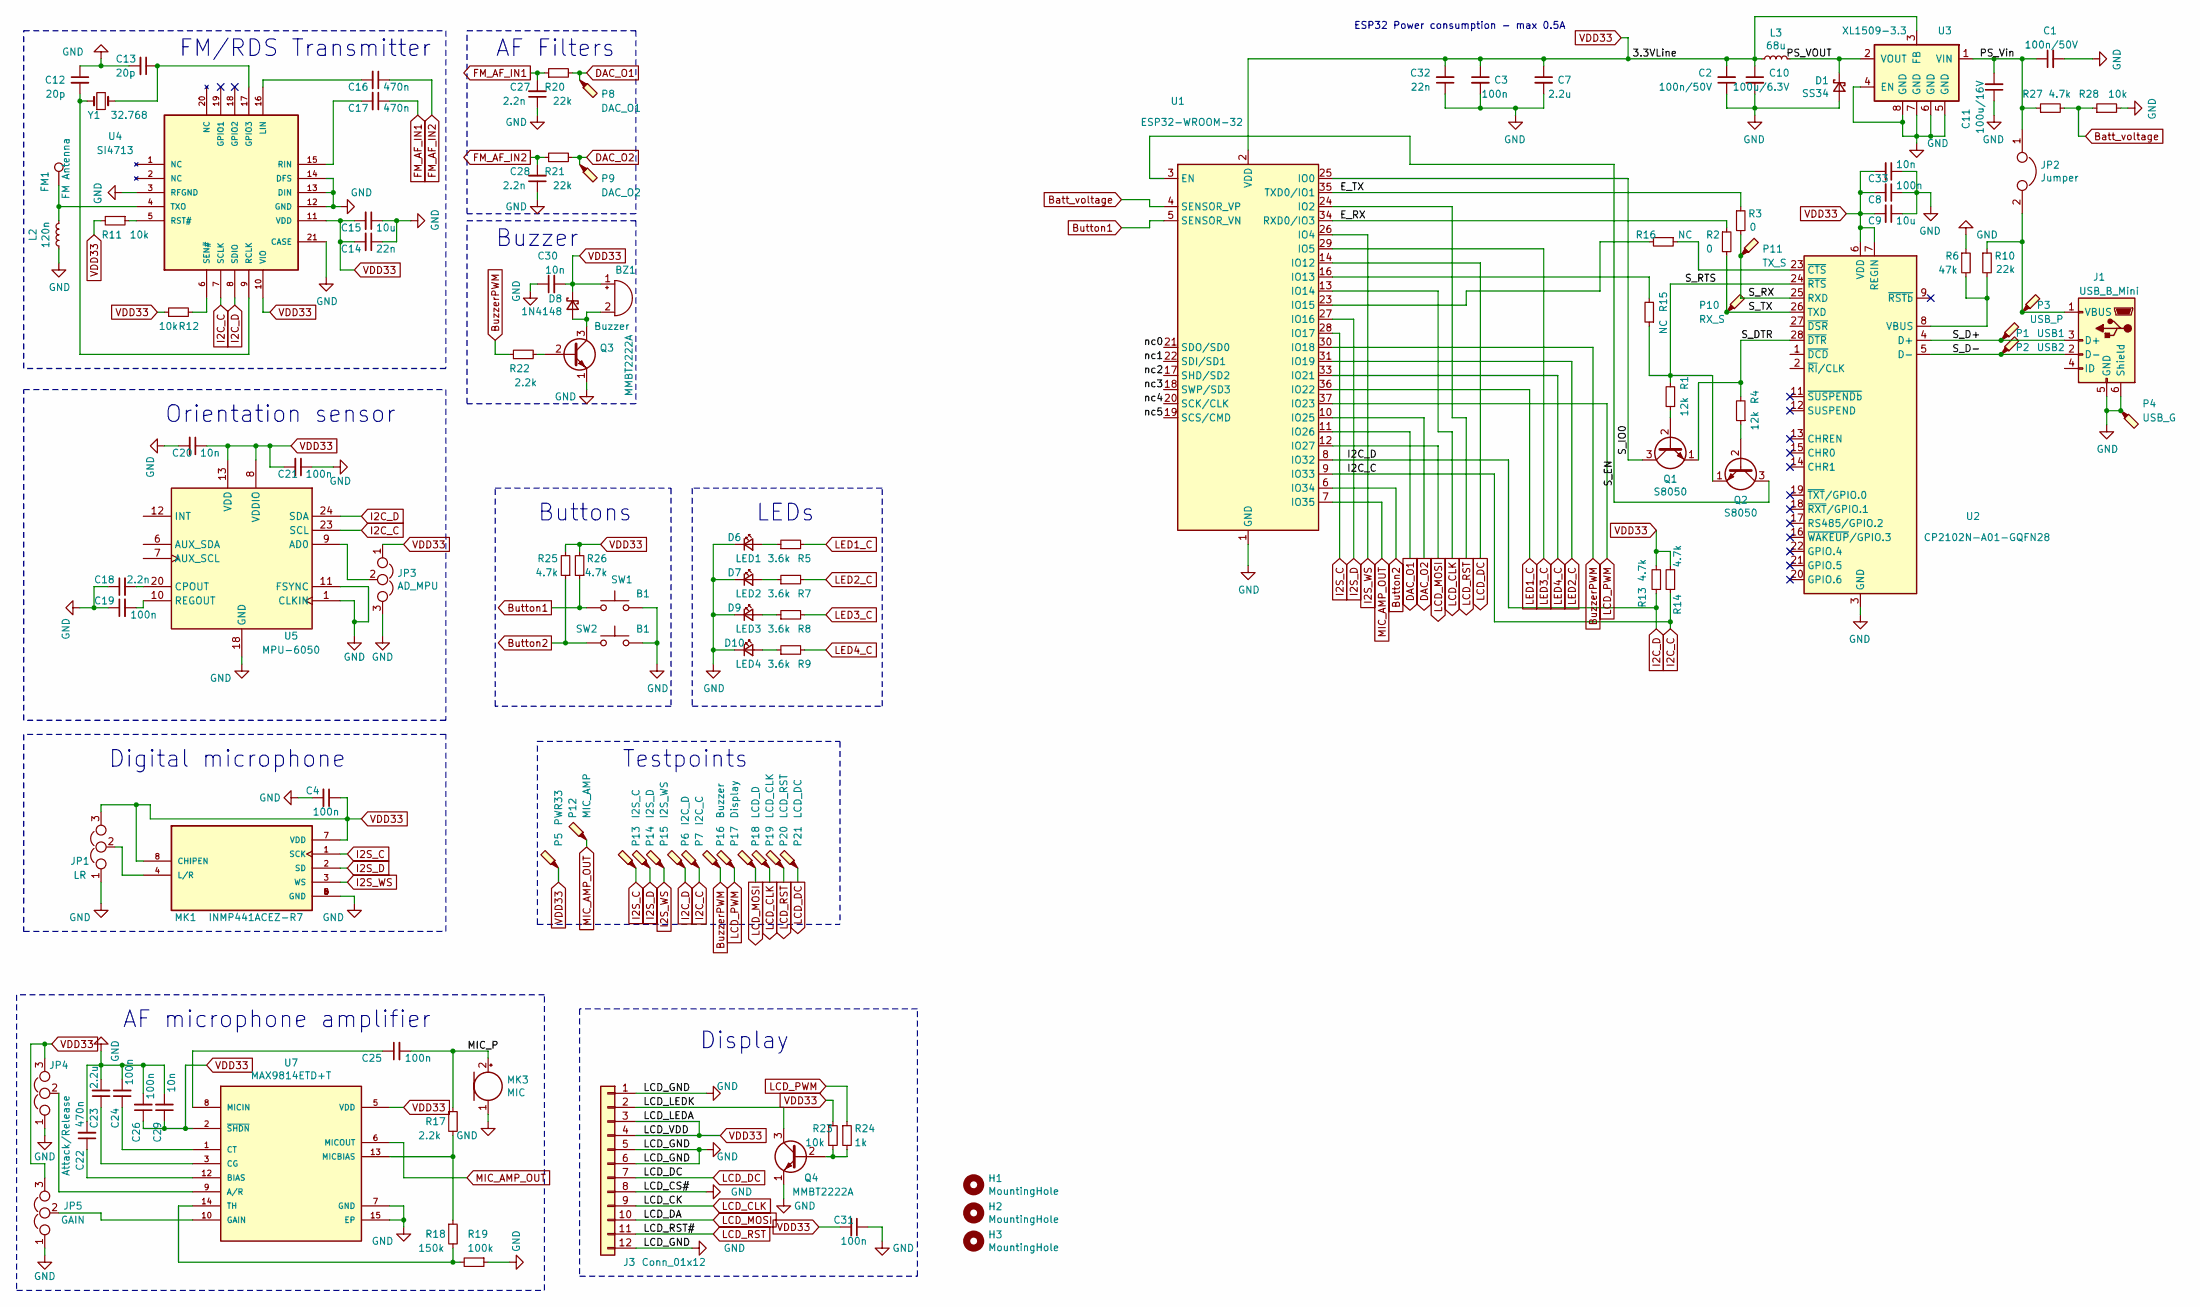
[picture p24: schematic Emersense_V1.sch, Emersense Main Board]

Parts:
BZ1: Buzzer; MLT-5030
C1, C2: 100n/50V; C_0805_2012Metric; Voltage 50V
C3, C4, C8, C19, C21, C31: 100n; C_0402_1005Metric
C7, C23: 2.2u; C_0603_1608Metric
C9: 10u; C_0805_2012Metric
C10: 100u/6.3V; C_1210_3225Metric; Voltage 6.3V
C11: 100u/16V; C_1210_3225Metric; Voltage 16V
C12, C13: 20p; C_0402_1005Metric; Voltage 50V
C14, C32: 22n; C_0402_1005Metric
C15: 10u; C_0603_1608Metric
C16, C17, C22: 470n; C_0603_1608Metric; Voltage 10V
C18: 2.2n; C_0603_1608Metric; Voltage 50V
C20, C30: 10n; C_0402_1005Metric; Voltage 50V
C24, C25, C26: 100n; C_0603_1608Metric; Voltage 50V
C27, C28: 2.2n; C_0402_1005Metric; Voltage 50V
C29: 10n; C_0603_1608Metric; Voltage 50V
C33: 10n; C_0805_2012Metric; Voltage 50V
D1: SS34; SOD-123FL
D6: LED1; D_0402_1005Metric
D7: LED2; D_0402_1005Metric
D8: 1N4148; D_SOD-523
D9: LED3; D_0402_1005Metric
D10: LED4; D_0402_1005Metric
FM1: FM Antenna; TestPoint_THTPad_1.0x1.0mm_Drill0.5mm
H1, H2, H3: MountingHole; M1_screw
J1: USB_B_Mini; U-M-M5DS-W-4
J3: Conn_01x12; SCREEN_Footprint_extended
JP1: LR; 3_jumper_1
JP2: Jumper; SolderJumper-2_P1.3mm_Open_RoundedPad1.0x1.5mm
JP3: AD_MPU; 3_jumper_1
JP4: Attack/Release; 3_jumper_1
JP5: GAIN; 3_jumper_1
L2: 120n; L_0402_1005Metric
L3: 68u; SWPA5040S680MT
MK1: INMP441ACEZ-R7; MIC_INMP441ACEZ-R7; PARTREV 1.1
MK3: MIC; B4013AM423-093
P1: USB1; TestPoint_Pad_D1.0mm
P2: USB2; TestPoint_Pad_D1.0mm
P3: USB_P; TestPoint_Pad_D1.0mm
P4: USB_G; TestPoint_Pad_D1.0mm
P5: PWR33; TestPoint_Pad_D1.0mm
P6: I2C_D; TestPoint_Pad_D1.0mm
P7: I2C_C; TestPoint_Pad_D1.0mm
P8: DAC_O1; TestPoint_Pad_D1.0mm
P9: DAC_O2; TestPoint_Pad_D1.0mm
P10: RX_S; TestPoint_Pad_D1.0mm
P11: TX_S; TestPoint_Pad_D1.0mm
P12: MIC_AMP; TestPoint_Pad_D1.0mm
P13: I2S_C; TestPoint_Pad_D1.0mm
P14: I2S_D; TestPoint_Pad_D1.0mm
P15: I2S_WS; TestPoint_Pad_D1.0mm
P16: Buzzer; TestPoint_Pad_D1.0mm
P17: Display; TestPoint_Pad_D1.0mm
P18: LCD_D; TestPoint_Pad_D1.0mm
P19: LCD_CLK; TestPoint_Pad_D1.0mm
P20: LCD_RST; TestPoint_Pad_D1.0mm
P21: LCD_DC; TestPoint_Pad_D1.0mm
Q1, Q2: S8050; SOT-23-R
Q3, Q4: MMBT2222A; SOT-23-R
R1, R4: 12k; R_0402_1005Metric
R2, R3: 0; R_0402_1005Metric
R5, R7, R8, R9: 3.6k; R_0402_1005Metric
R6: 47k; R_0402_1005Metric
R10, R20, R21: 22k; R_0402_1005Metric
R11, R12, R23, R28: 10k; R_0402_1005Metric
R13, R14, R25, R26, R27: 4.7k; R_0402_1005Metric
R15, R16: NC; R_0402_1005Metric
R17, R22: 2.2k; R_0402_1005Metric
R18: 150k; R_0402_1005Metric
R19: 100k; R_0402_1005Metric
R24: 1k; R_0402_1005Metric
SW1, SW2: B1; TS-1086E
U1: ESP32-WROOM-32
U2: CP2102N-A01-GQFN28; QFN-28-1EP_5x5mm_P0.5mm_EP3.35x3.35mm
U3: XL1509-3.3; SOP-8_3.76x4.96mm_P1.27mm
U4: SI4713; QFN50P300X300X60-21N
U5: MPU-6050; InvenSense_QFN-24_4x4mm_P0.5mm
U7: MAX9814ETD+T; DFN-14-1EP_3x3mm_P0.4mm_EP1.78x2.35mm; PARTREV 3
Y1: 32.768; Crystal_SMD_G8-2Pin_3.2x1.5mm

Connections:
/E_RX: R2.1, U1.34 (RXD0/IO3)
/E_TX: R3.1, U1.35 (TXD0/IO1)
/LCD_LEDK: J3.2, Q4.3 (C)
/MIC_P: C25.2, MK3.2 (+), R17.1
/PS_VOUT: D1.1 (K), L3.1, U3.2 (VOUT)
/PS_Vin: C1.1, C11.2, JP2.1, R27.1, U3.1 (VIN)
/S_D+: J1.3 (D+), P1.1, U2.4 (D+)
/S_D-: J1.2 (D-), P2.1, U2.5 (D-)
/S_DTR: Q1.1 (E), R4.2, U2.28 (~DTR)
/S_EN: Q2.3 (C), U1.3 (EN)
/S_IO0: Q1.3 (C), U1.25 (IO0)
/S_RTS: Q2.1 (E), R1.2, R15.1, U2.24 (~RTS)
/S_RX: P11.1, R3.2, U2.25 (RXD)
/S_TX: P10.1, R2.2, U2.26 (TXD)
/nc0: U1.21 (SDO/SD0)
/nc1: U1.22 (SDI/SD1)
/nc2: U1.17 (SHD/SD2)
/nc3: U1.18 (SWP/SD3)
/nc4: U1.20 (SCK/CLK)
/nc5: U1.19 (SCS/CMD)
Batt_voltage: R27.2, R28.1, U1.4 (SENSOR_VP)
Button1: R26.1, SW1.1, U1.5 (SENSOR_VN)
Button2: R25.1, SW2.1, U1.6 (IO34)
BuzzerPWM: P16.1, R22.1, U1.30 (IO18)
DAC_O1: P8.1, R20.2, U1.11 (IO26)
DAC_O2: P9.1, R21.2, U1.10 (IO25)
FM_AF_IN1: C17.1, C27.2, R20.1
FM_AF_IN2: C16.1, C28.2, R21.1
GND: C1.2, C2.1, C3.2, C4.2, C7.2, C8.1, C9.1, C10.2, C11.1, C12.1, C13.2, C14.1, C15.1, C18.1, C19.1, C20.2, C21.1, C22.2, C23.2, C24.2, C26.2, C27.1, C28.1, C29.2, C30.1, C31.1, C32.1, C33.1, D1.2 (A), D6.1 (K), D7.1 (K), D9.1 (K), D10.1 (K), J1.5 (GND), J1.6 (Shield), J3.1, J3.5, J3.6, J3.8, J3.12, JP1.1, JP3.3, JP4.1, JP5.1, L2.2, MK1.5 (GND), MK1.6 (GND), MK1.9 (GND), MK3.1 (-), P4.1, Q3.1 (E), Q4.1 (E), R6.1, R19.1, R28.2, SW1.2, SW2.2, U1.1 (GND), U1.15 (GND), U1.38 (GND), U1.39 (GND), U2.3 (GND), U2.29 (GND), U3.4 (EN), U3.5 (GND), U3.6 (GND), U3.7 (GND), U3.8 (GND), U4.3 (RFGND), U4.12 (GND), U4.13 (DIN), U4.14 (DFS), U4.21 (CASE), U5.1 (CLKIN), U5.11 (FSYNC), U5.18 (GND), U7.7 (GND), U7.15 (EP)
I2C_C: P7.1, R14.1, U1.9 (IO33), U4.7 (SCLK), U5.23 (SCL)
I2C_D: P6.1, R13.1, U1.8 (IO32), U4.8 (SDIO), U5.24 (SDA)
I2S_C: MK1.1 (SCK), P13.1, U1.28 (IO17)
I2S_D: MK1.2 (SD), P14.1, U1.27 (IO16)
I2S_WS: MK1.3 (WS), P15.1, U1.26 (IO4)
LCD_CLK: J3.9, P19.1, U1.13 (IO14)
LCD_DC: J3.7, P21.1, U1.14 (IO12)
LCD_MOSI: J3.10, P18.1, U1.12 (IO27)
LCD_PWM: P17.1, R24.1, U1.37 (IO23)
LCD_RST: J3.11, P20.1, U1.24 (IO2)
LED1_C: R5.2, U1.36 (IO22)
LED2_C: R7.2, U1.31 (IO19)
LED3_C: R8.2, U1.29 (IO5)
LED4_C: R9.2, U1.33 (IO21)
MIC_AMP_OUT: P12.1, U1.7 (IO35), U7.6 (MICOUT)
unnamed: BZ1.2 (+), D8.2 (A), Q3.3 (C)
unnamed: C12.2, U4.9 (RCLK), Y1.1
unnamed: C13.1, U4.17 (GPIO3), Y1.2
unnamed: C16.2, U4.16 (LIN)
unnamed: C17.2, U4.15 (RIN)
unnamed: C18.2, U5.20 (CPOUT)
unnamed: C19.2, U5.10 (REGOUT)
unnamed: C22.1, U7.12 (BIAS)
unnamed: C23.1, U7.3 (CG)
unnamed: C24.1, U7.1 (CT)
unnamed: C25.1, U7.8 (MICIN)
unnamed: D6.2 (A), R5.1
unnamed: D7.2 (A), R7.1
unnamed: D9.2 (A), R8.1
unnamed: D10.2 (A), R9.1
unnamed: FM1.1, L2.1, U4.4 (TXO)
unnamed: J1.1 (VBUS), JP2.2, P3.1, R10.1
unnamed: JP1.2, MK1.4 (L/R)
unnamed: JP3.2, U5.9 (AD0)
unnamed: JP4.2, U7.9 (A/R)
unnamed: JP5.2, U7.10 (GAIN)
unnamed: Q1.2 (B), R1.1
unnamed: Q2.2 (B), R4.1
unnamed: Q3.2 (B), R22.2
unnamed: Q4.2 (B), R23.2, R24.2
unnamed: R6.2, R10.2, U2.8 (VBUS)
unnamed: R11.1, U4.5 (RST#)
unnamed: R12.2, U4.6 (SEN#)
unnamed: R15.2, U1.16 (IO13)
unnamed: R16.1, U2.23 (~CTS)
unnamed: R16.2, U1.23 (IO15)
unnamed: R17.2, R18.1, U7.13 (MICBIAS)
unnamed: R18.2, R19.2, U7.14 (TH)
VDD33: BZ1.1 (-), C2.2, C3.1, C4.1, C7.1, C8.2, C9.2, C10.1, C14.2, C15.2, C20.1, C21.2, C26.1, C29.1, C30.2, C31.2, C32.2, C33.2, D8.1 (K), J3.3, J3.4, JP1.3, JP3.1, JP4.3, JP5.3, L3.2, MK1.7 (VDD), MK1.8 (CHIPEN), P5.1, R11.2, R12.1, R13.2, R14.2, R23.1, R25.2, R26.2, U1.2 (VDD), U2.6 (VDD), U2.7 (REGIN), U3.3 (FB), U4.10 (VIO), U4.11 (VDD), U5.8 (VDDIO), U5.13 (VDD), U7.2 (~SHDN), U7.5 (VDD)

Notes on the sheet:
ESP32 Power consumption - max 0.5A
AF Filters
FM/RDS Transmitter
Buzzer
Testpoints
Orientation sensor
Digital microphone
AF microphone amplifier
Display
LEDs
Buttons

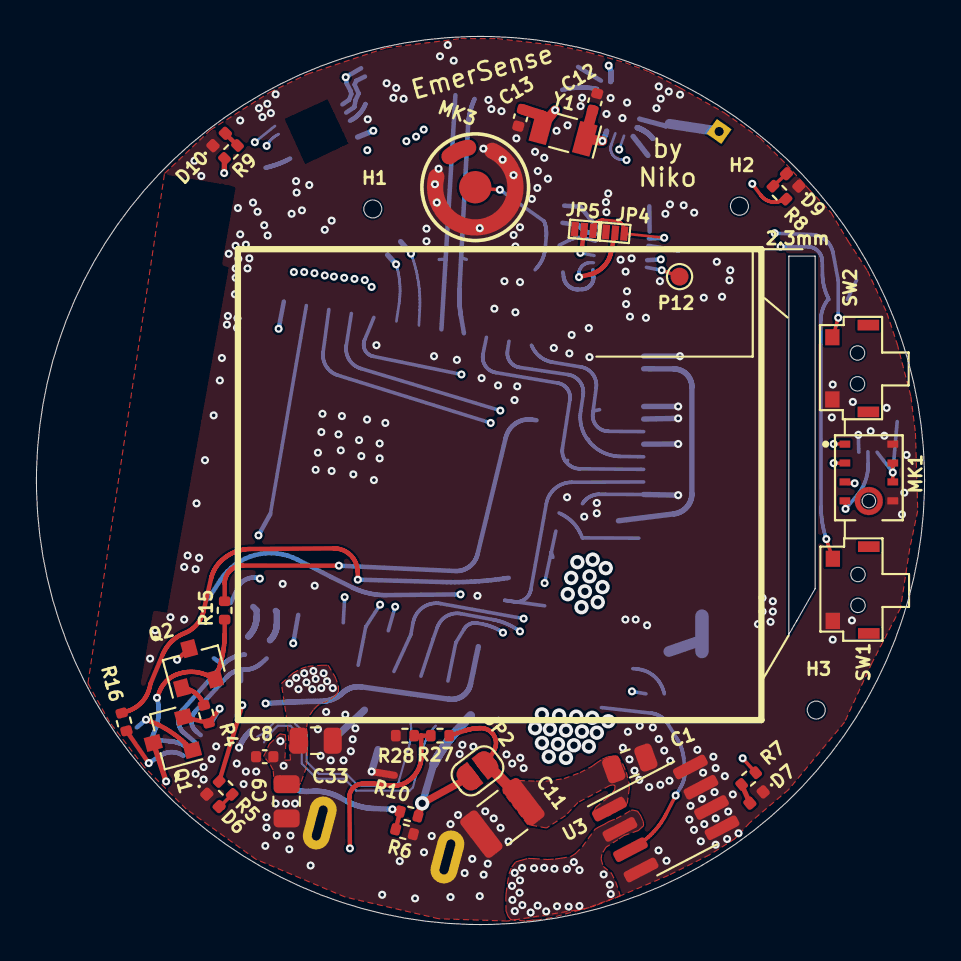
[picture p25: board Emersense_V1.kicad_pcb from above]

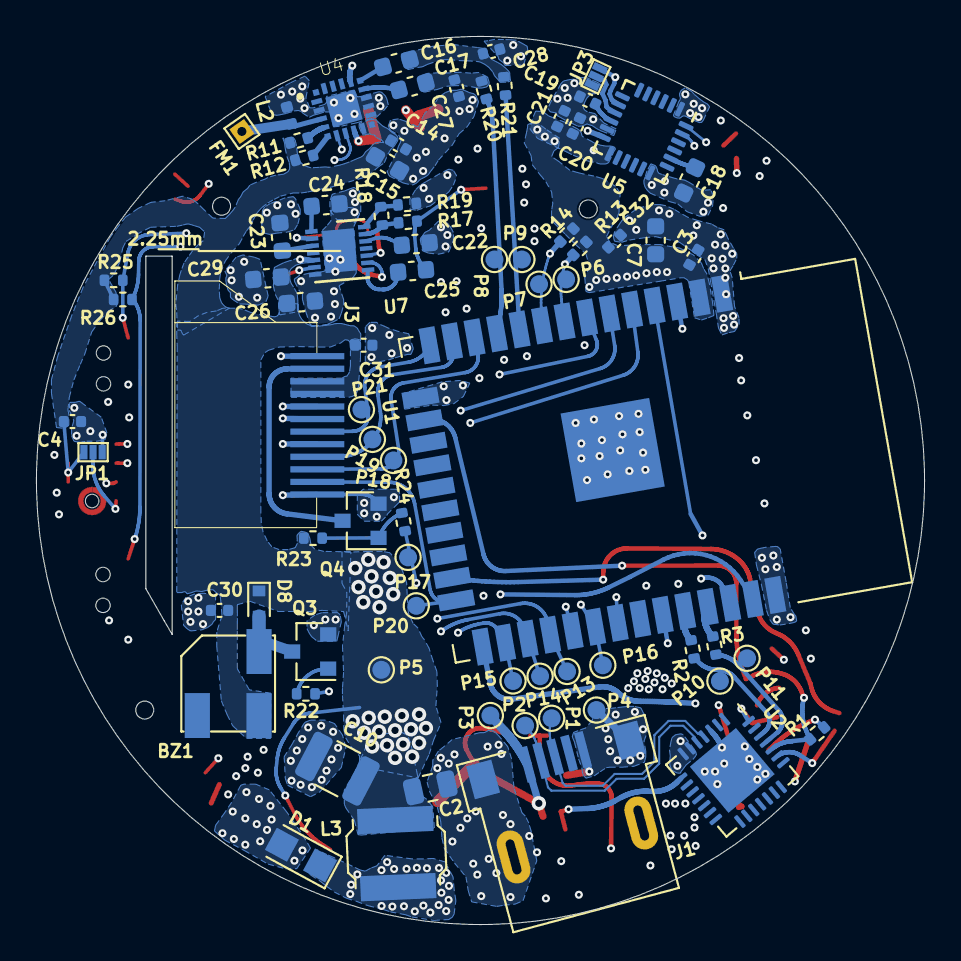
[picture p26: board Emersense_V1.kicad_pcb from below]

Board: 4 copper layers, 49.3 x 49.3 mm, 115 parts (78 on the bottom side), 72 nets.
